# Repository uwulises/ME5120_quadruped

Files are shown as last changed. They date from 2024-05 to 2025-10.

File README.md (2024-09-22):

# ME5120_quadruped
Este proyecto pretende diseñar y fabricar un cuadrúpedo autónomo. La primera etapa corresponde a seleccionar y diseñar el hardware adecuado para montar una estructura funcional.
Las siguientes etapas se centrarán en el control de la caminata y planificación/navegación del entorno.

## TODO
- [x] PCB design
- [x] Basic motor control
- [ ] SPI leg communication
- [ ] UART legs communication
- [ ] MQTT wireless moves callback
- [ ] MuJoCo model update
- [ ] ROS2 model

# Design

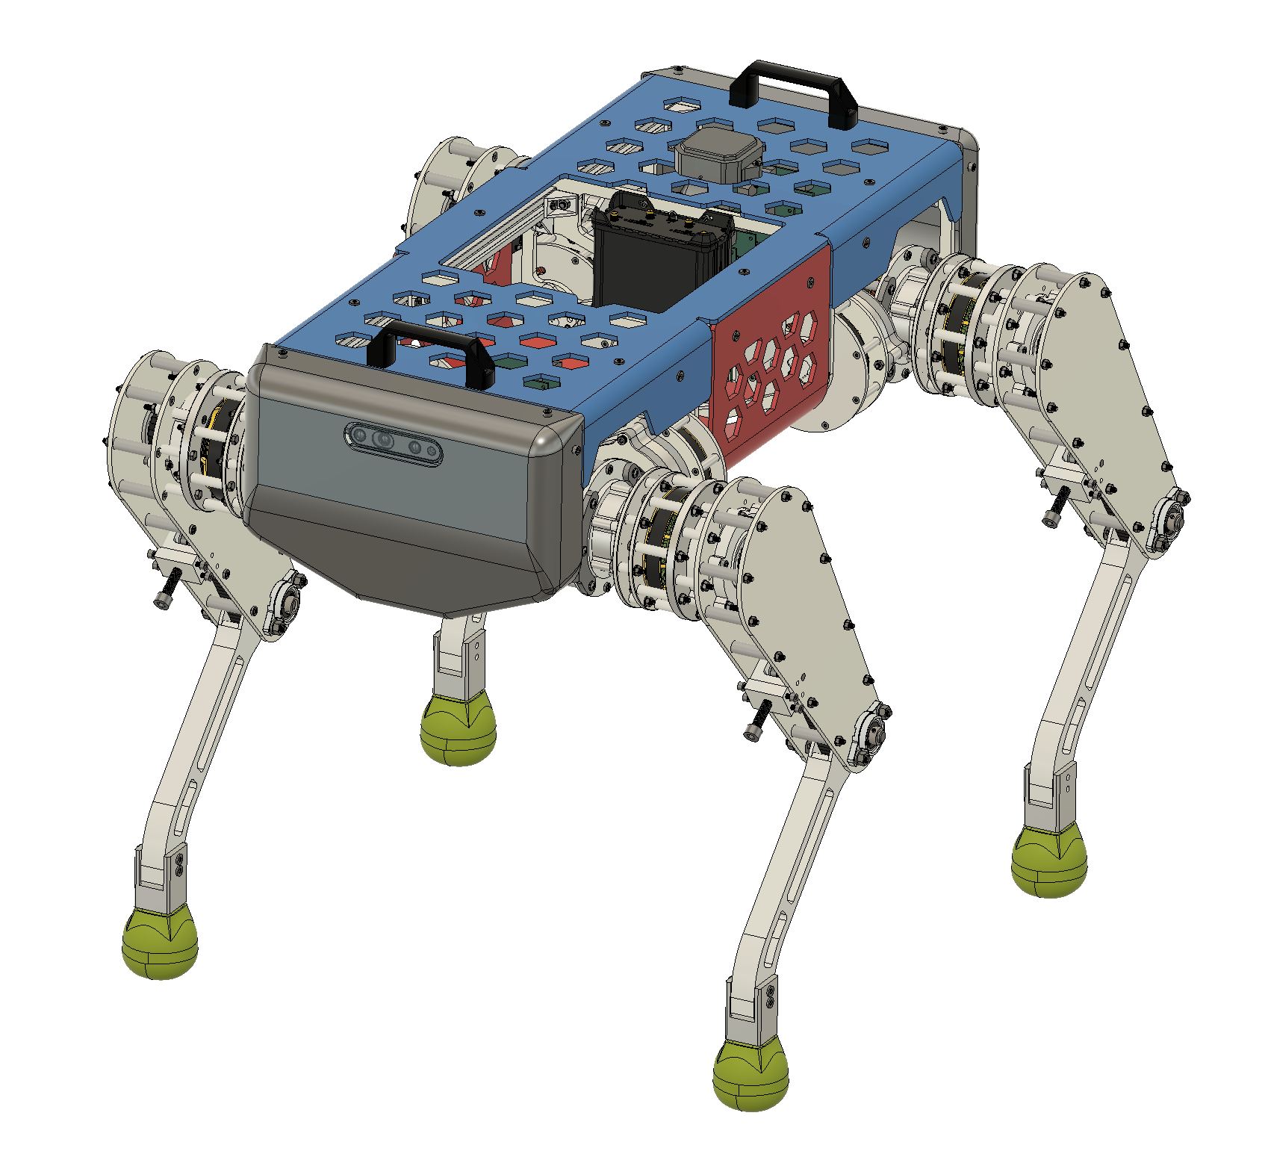
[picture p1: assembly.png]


# Hardware

## Driver + Rpi Pico Hat
En esta versión se propone utilizar el driver texas drv8302 junto a la [librería SimpleFOC](https://docs.simplefoc.com/drv8302_example)
### SimpleFOC example


### Hat schematic
 
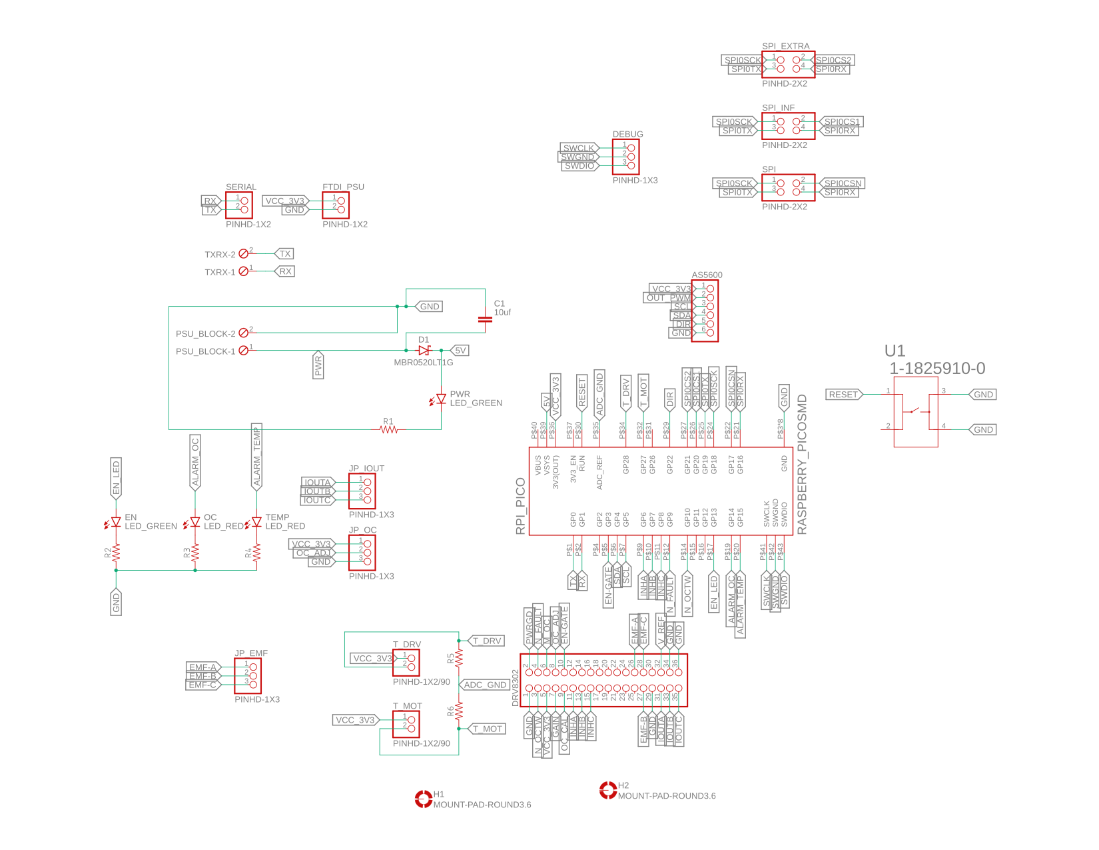
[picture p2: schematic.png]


### Hat Board

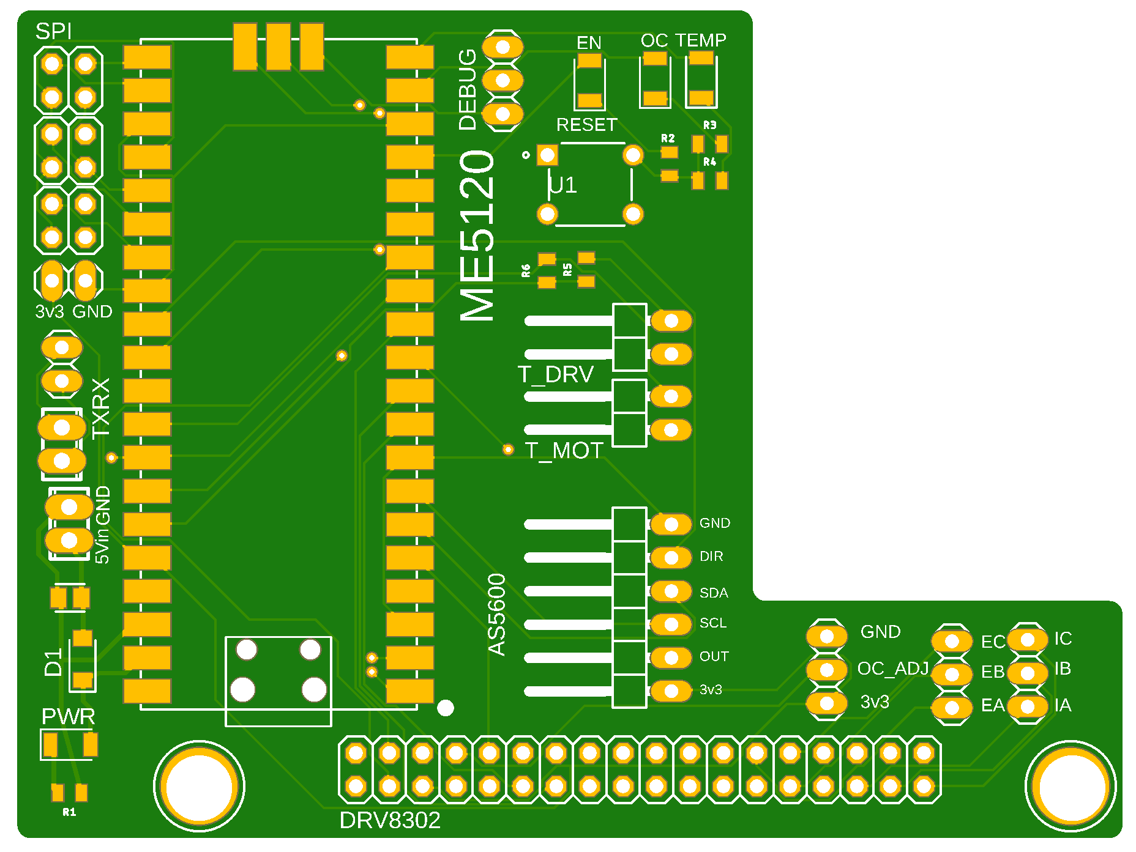
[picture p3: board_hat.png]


## Simulation - Mujoco
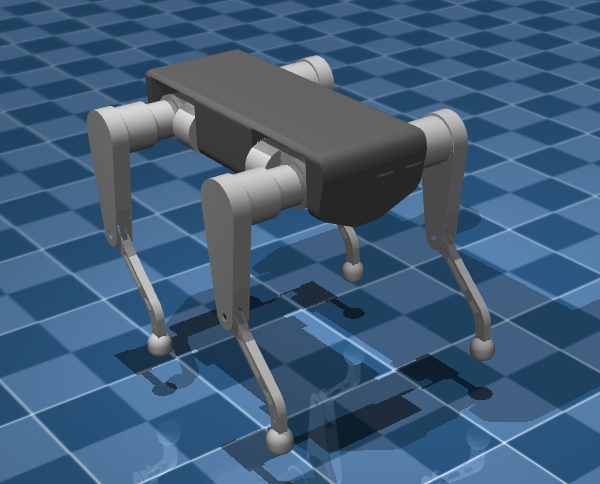
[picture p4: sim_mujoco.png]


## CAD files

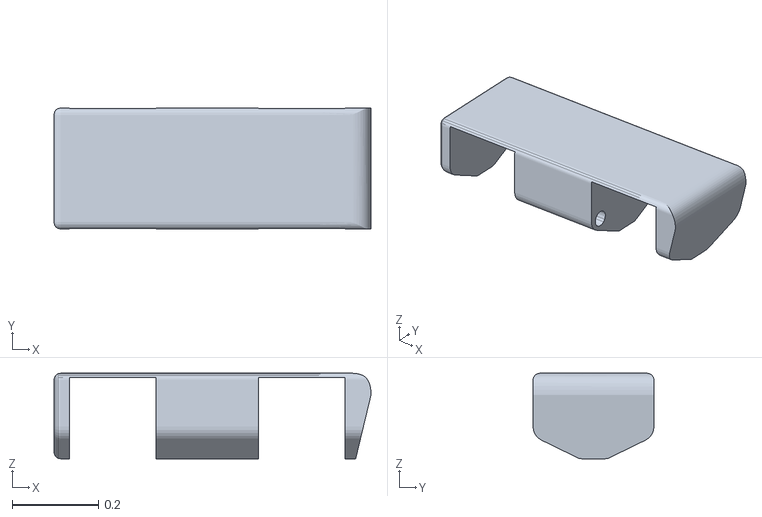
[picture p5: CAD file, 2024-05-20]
model/assets/trunk_franki.obj
0.734 x 0.28 x 0.198

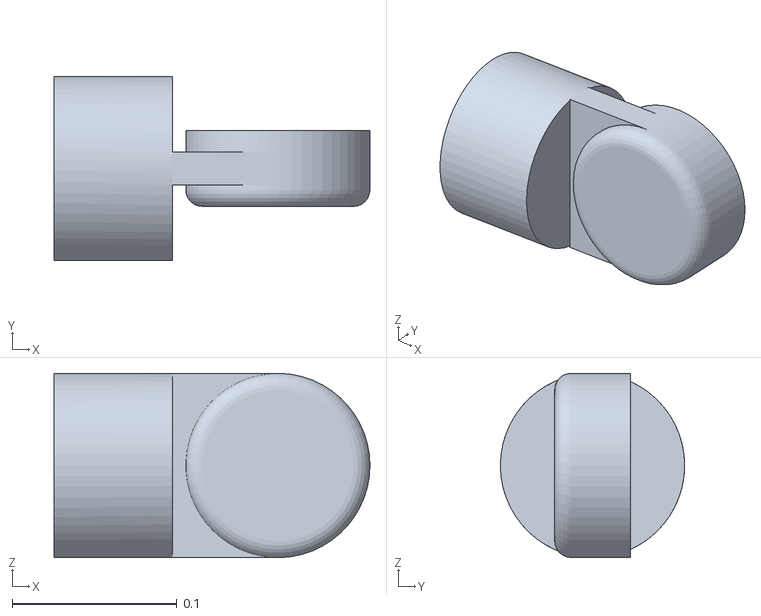
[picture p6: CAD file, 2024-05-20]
model/assets/hip_franki.obj
0.192 x 0.112 x 0.112

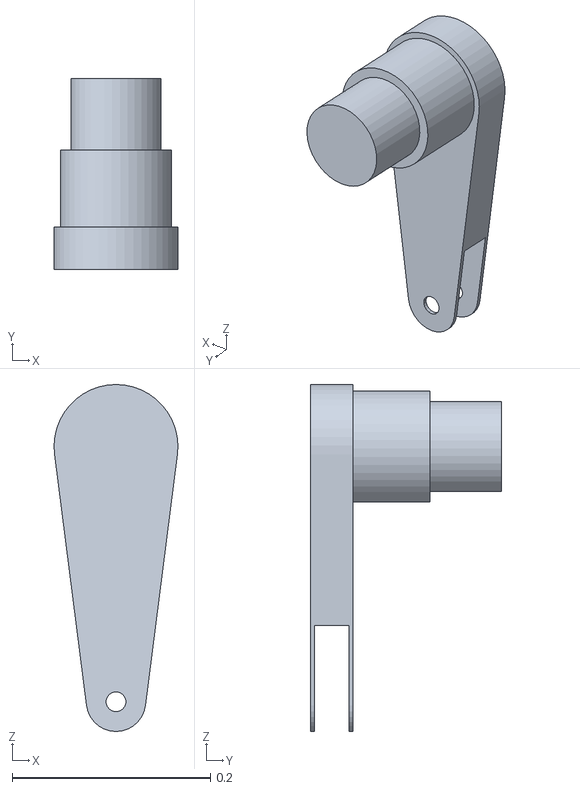
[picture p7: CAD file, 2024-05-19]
model/assets/thigh_mirror_franki.obj
0.125 x 0.193 x 0.35

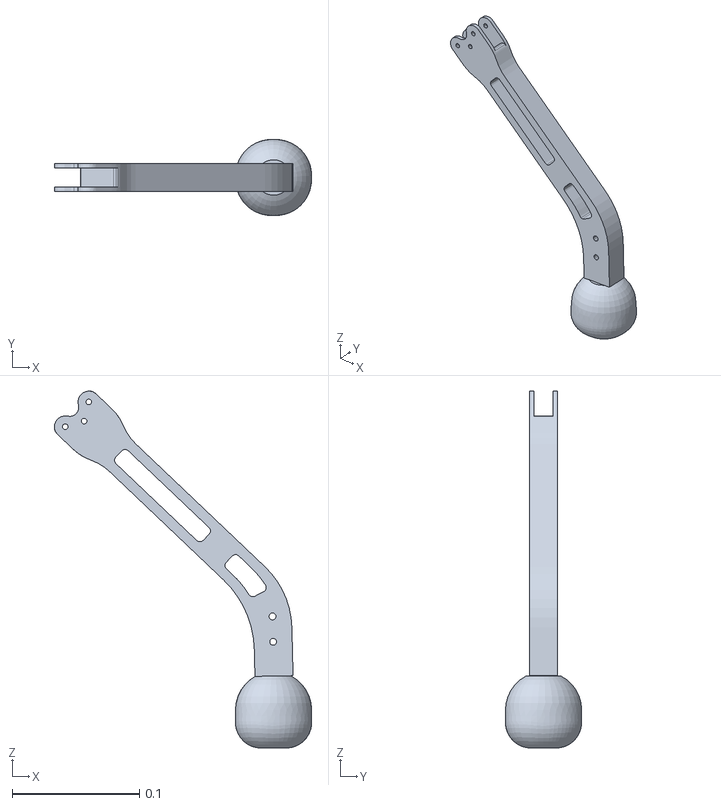
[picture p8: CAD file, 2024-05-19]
model/assets/calf_franki.obj
0.202 x 0.06 x 0.281

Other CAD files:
model/assets/thigh_franki.obj

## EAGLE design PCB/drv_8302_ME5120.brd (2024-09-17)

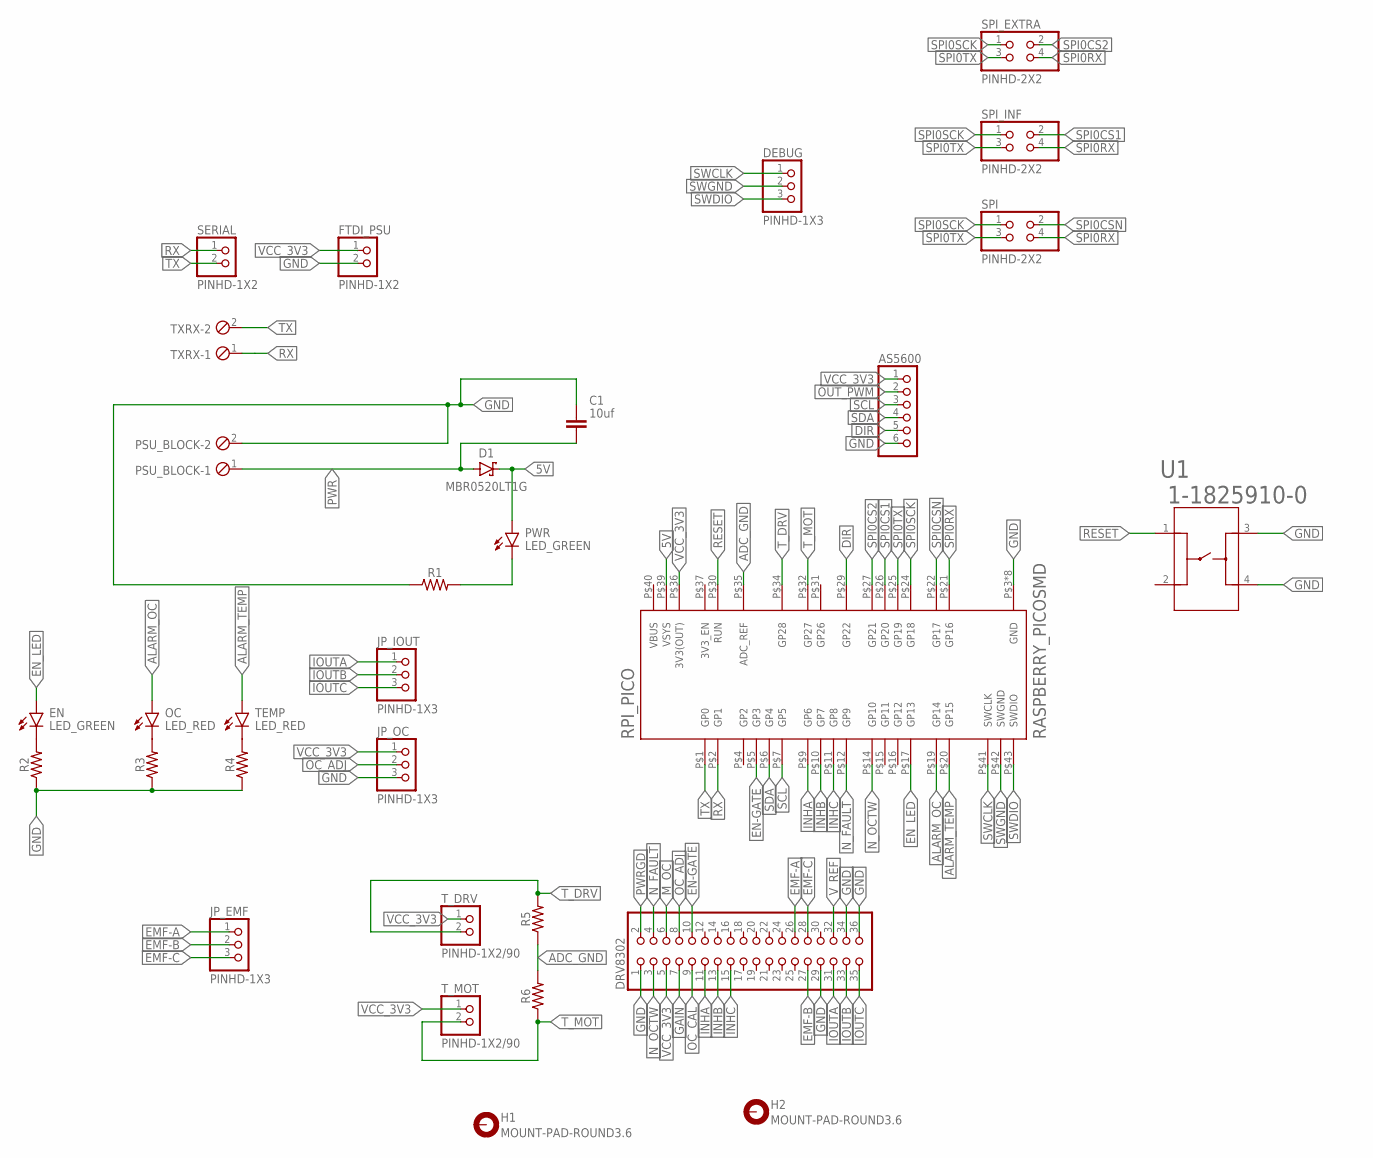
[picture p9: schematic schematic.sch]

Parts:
AS5600: PINHD-1X6/90; 1X06/90
C1: 10uf; CAPC2012X110
D1: MBR0520LT1G; SODFL3718X115
DEBUG: PINHD-1X3; 1X03
DRV8302: PINHD-2X18; 2X18
EN: LED_GREEN; LEDC3216X75N_FLAT-G
FTDI_PSU: PINHD-1X2; 1X02
H1, H2: MOUNT-PAD-ROUND3.6; 3,6-PAD
JP_EMF: PINHD-1X3; 1X03
JP_IOUT: PINHD-1X3; 1X03
JP_OC: PINHD-1X3; 1X03
OC: LED_RED; LEDC3216X75N_FLAT-R
PSU_BLOCK: MPT2; 2POL254
PWR: LED_GREEN; LEDC3216X75N_FLAT-G
R1, R2, R3, R4, R5, R6: 0805
RPI_PICO: RASPBERRY_PICOSMD; PICO-PKG-SMD
SERIAL: PINHD-1X2; 1X02
SPI: PINHD-2X2; 2X02
SPI_EXTRA: PINHD-2X2; 2X02
SPI_INF: PINHD-2X2; 2X02
TEMP: LED_RED; LEDC3216X75N_FLAT-R
TXRX: MPT2; 2POL254
T_DRV: PINHD-1X2/90; 1X02/90
T_MOT: PINHD-1X2/90; 1X02/90
U1: 1-1825910-0; SWITCH_1-1825910-0

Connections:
5V: D1.1 (C), PWR.A, RPI_PICO.P$39 (VSYS)
ADC_GND: R5.1, R6.2, RPI_PICO.P$35 (ADC_REF)
ALARM_OC: OC.A, RPI_PICO.P$19 (GP14)
ALARM_TEMP: RPI_PICO.P$20 (GP15), TEMP.A
DIR: AS5600.5, RPI_PICO.P$29 (GP22)
EMF-A: DRV8302.26, JP_EMF.1
EMF-B: DRV8302.27, JP_EMF.2
EMF-C: DRV8302.28, JP_EMF.3
EN-GATE: DRV8302.10, RPI_PICO.P$5 (GP3)
EN_LED: EN.A, RPI_PICO.P$17 (GP13)
GAIN: DRV8302.7
GND: AS5600.6, C1.1, DRV8302.1, DRV8302.29, DRV8302.34, DRV8302.36, FTDI_PSU.2, JP_OC.3, PSU_BLOCK.2, R1.1, R2.1, R3.1, R4.1, RPI_PICO.P$3 (GND), RPI_PICO.P$8 (GND), RPI_PICO.P$13 (GND), RPI_PICO.P$18 (GND), RPI_PICO.P$23 (GND), RPI_PICO.P$28 (GND), RPI_PICO.P$33 (GND), RPI_PICO.P$38 (GND), U1.3, U1.4
INHA: DRV8302.11, RPI_PICO.P$9 (GP6)
INHB: DRV8302.13, RPI_PICO.P$10 (GP7)
INHC: DRV8302.15, RPI_PICO.P$11 (GP8)
IOUTA: DRV8302.31, JP_IOUT.1
IOUTB: DRV8302.33, JP_IOUT.2
IOUTC: DRV8302.35, JP_IOUT.3
M_OC: DRV8302.6
unnamed: PWR.C, R1.2
unnamed: OC.C, R3.2
unnamed: EN.C, R2.2
unnamed: R4.2, TEMP.C
N_FAULT: DRV8302.4, RPI_PICO.P$12 (GP9)
N_OCTW: DRV8302.3, RPI_PICO.P$14 (GP10)
OC_ADJ: DRV8302.8, JP_OC.2
OC_CAL: DRV8302.9
OUT_PWM: AS5600.2
PWR: C1.2, D1.2 (A), PSU_BLOCK.1
PWRGD: DRV8302.2
RESET: RPI_PICO.P$30 (RUN), U1.1
RX: RPI_PICO.P$2 (GP1), SERIAL.1, TXRX.1
SCL: AS5600.3, RPI_PICO.P$7 (GP5)
SDA: AS5600.4, RPI_PICO.P$6 (GP4)
SPI0CS1: RPI_PICO.P$26 (GP20), SPI_INF.2
SPI0CS2: RPI_PICO.P$27 (GP21), SPI_EXTRA.2
SPI0CSN: RPI_PICO.P$22 (GP17), SPI.2
SPI0RX: RPI_PICO.P$21 (GP16), SPI.4, SPI_EXTRA.4, SPI_INF.4
SPI0SCK: RPI_PICO.P$24 (GP18), SPI.1, SPI_EXTRA.1, SPI_INF.1
SPI0TX: RPI_PICO.P$25 (GP19), SPI.3, SPI_EXTRA.3, SPI_INF.3
SWCLK: DEBUG.1, RPI_PICO.P$41 (SWCLK)
SWDIO: DEBUG.3, RPI_PICO.P$43 (SWDIO)
SWGND: DEBUG.2, RPI_PICO.P$42 (SWGND)
TX: RPI_PICO.P$1 (GP0), SERIAL.2, TXRX.2
T_DRV: R5.2, RPI_PICO.P$34 (GP28), T_DRV.2
T_MOT: R6.1, RPI_PICO.P$32 (GP27), T_MOT.2
VBUS: RPI_PICO.P$40 (VBUS)
VCC_3V3: AS5600.1, DRV8302.5, FTDI_PSU.1, JP_OC.1, RPI_PICO.P$36 (3V3(OUT)), T_DRV.1, T_MOT.1
V_REF: DRV8302.32

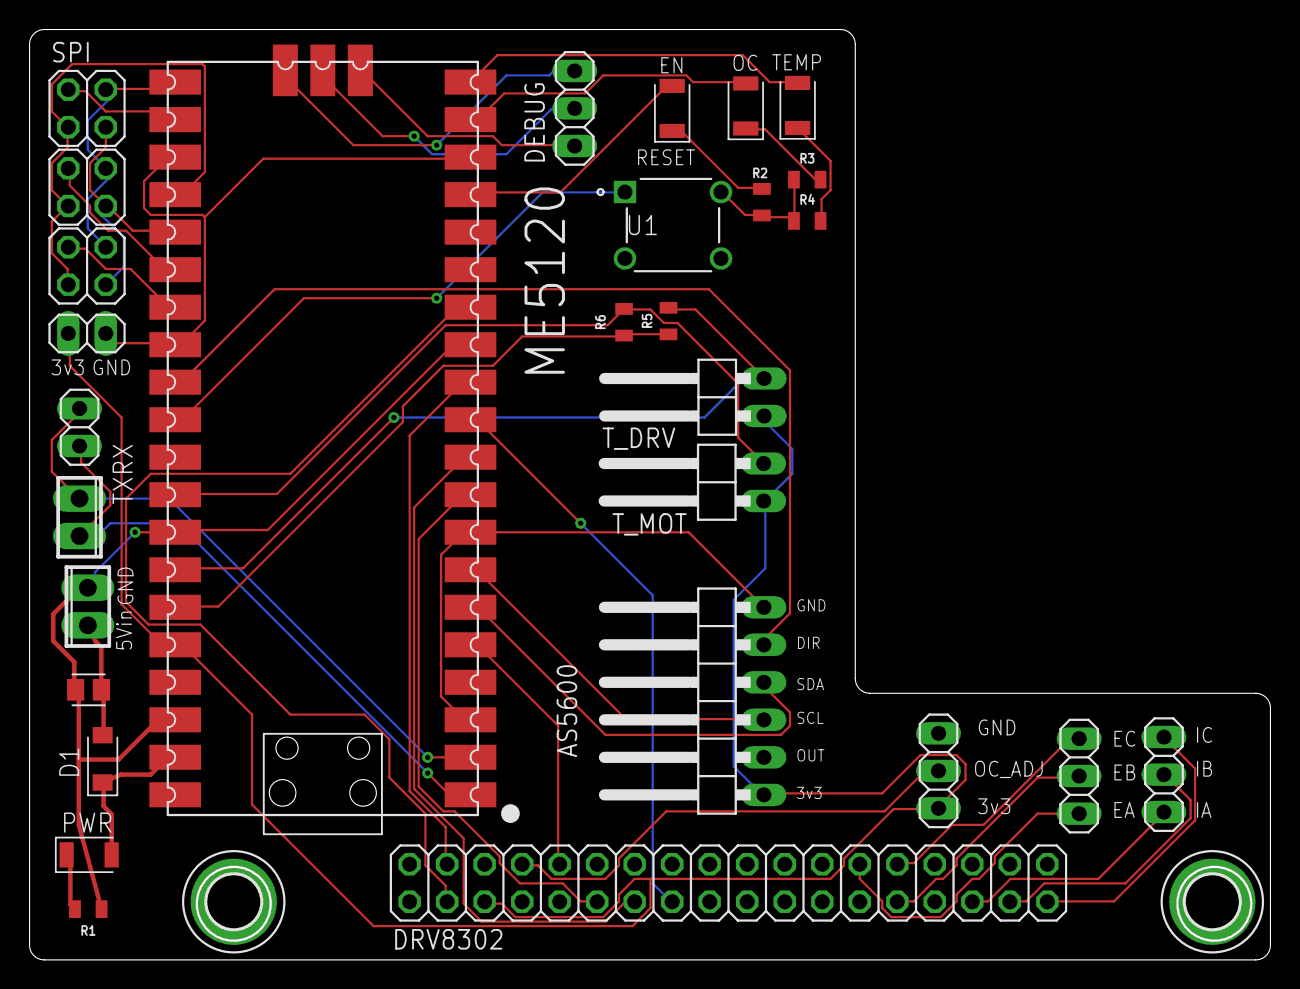
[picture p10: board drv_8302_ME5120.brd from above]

Board: 2 copper layers, 84.0 x 63.0 mm, 31 parts (0 on the bottom side), 42 nets.

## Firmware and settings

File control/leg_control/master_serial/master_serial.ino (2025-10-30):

#include <SoftwareSerial.h>

String inputString = "";      // a String to hold incoming data
bool stringComplete = false;  // whether the string is complete

SoftwareSerial FR(6, 7); // RX, TX
SoftwareSerial FL(8, 9); // RX, TX
SoftwareSerial RR(10,11); // RX, TX
SoftwareSerial RL(12, 13); // RX, TX

void serialEvent() {
  while (Serial.available()) {
    // get the new byte:
    char inChar = (char)Serial.read();
    // add it to the inputString:
    inputString += inChar;
    // if the incoming character is a newline, set a flag so the main loop can
    // do something about it:
    if (inChar == '\n') {
      stringComplete = true;
    }
  }
}

void setup() {
  // initialize serial:
  Serial.begin(9600);
  // reserve 200 bytes for the inputString:
  inputString.reserve(200);
  // set the data rate for the SoftwareSerial port
  FR.begin(4800);
  FL.begin(4800);
  RR.begin(4800);
  RL.begin(4800);
}

void loop() { // run over and over
// print the string when a newline arrives:
  if (stringComplete) {
    if (inputString.substring(0, 4) == "HOME") {
      FR.print("T000000000\n");
      FL.print("T000000000\n");
      RR.print("T000000000\n");
      RL.print("T000000000\n");
    }
    // clear the string:
    inputString = "";
    stringComplete = false;
  }
}

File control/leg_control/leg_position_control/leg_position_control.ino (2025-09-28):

#include "spi_msg.h"
#include "drv.h"


String inputString = "";
bool stringComplete = false;

uint8_t hombro_target = 0;
uint8_t hombro_pos = 0;
uint8_t sup_target = 0;
uint8_t sup_pos = 0;
uint8_t inf_target = 0;
uint8_t inf_pos = 0;

void serialEvent() {
  while (Serial.available()) {
    // get the new byte:
    char inChar = (char)Serial.read();
    // add it to the inputString:
    inputString += inChar;
    // if the incoming character is a newline, set a flag so the main loop can
    // do something about it:
    if (inChar == '\n') {
      stringComplete = true;
    }
  }
}


void setup() {
  // put your setup code here, to run once:
  Serial.begin(115200);
  sleep_ms(2000);
  drv_setup();
  Serial.println("SPI Master with 2 slaves\n");
  spi_master_init();  // setup once
}

void loop() {
  // main FOC algorithm function
  motor_loop();
  serialEvent();
  // put your main code here, to run repeatedly:

  if (stringComplete) {
    if (inputString.substring(0, 1) == "T") {
      Serial.println(inputString);
      hombro_target = inputString.substring(1, 4).toInt();
      sup_target = inputString.substring(4, 7).toInt();
      inf_target = inputString.substring(7, 11).toInt();
      if (spi_is_writable(spi_default)){
      sup_pos=spi_exchange_angle(CS_SLAVE1, sup_target);
      //inf_pos=spi_exchange_angle(CS_SLAVE2, inf_target);
      }
      Serial.println(hombro_target);
      Serial.println(sup_target);
      Serial.println(inf_target);
      Serial.println(sup_pos);
      Serial.println(inf_pos);
      update_target(hombro_target);
      inputString = "";
      stringComplete = false;
    }
    inputString = "";
    stringComplete = false;
  }
}

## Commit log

2024-04-22 add folders and basic motor definition
2024-04-22 add schematic
2024-04-27 add init align voltage
2024-04-27 update schematic
2024-05-19 add meshes for simulation
    [calf_franki.obj, hip.obj, thigh.obj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]
2024-05-20 update meshes with actual model
    [hip_franki.obj]
2024-07-13 tested with pcb
2024-07-17 add test for leds
2025-09-26 add SDK SPI
2025-09-27 add joint control for 3 devices
2025-09-28 add peripheral device control
2025-09-28 working message to one slave device using 8bit position target
2025-09-28 add test files for leg control

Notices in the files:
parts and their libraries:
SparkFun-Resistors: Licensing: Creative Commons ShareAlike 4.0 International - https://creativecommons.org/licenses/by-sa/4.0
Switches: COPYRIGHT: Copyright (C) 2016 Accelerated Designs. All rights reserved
